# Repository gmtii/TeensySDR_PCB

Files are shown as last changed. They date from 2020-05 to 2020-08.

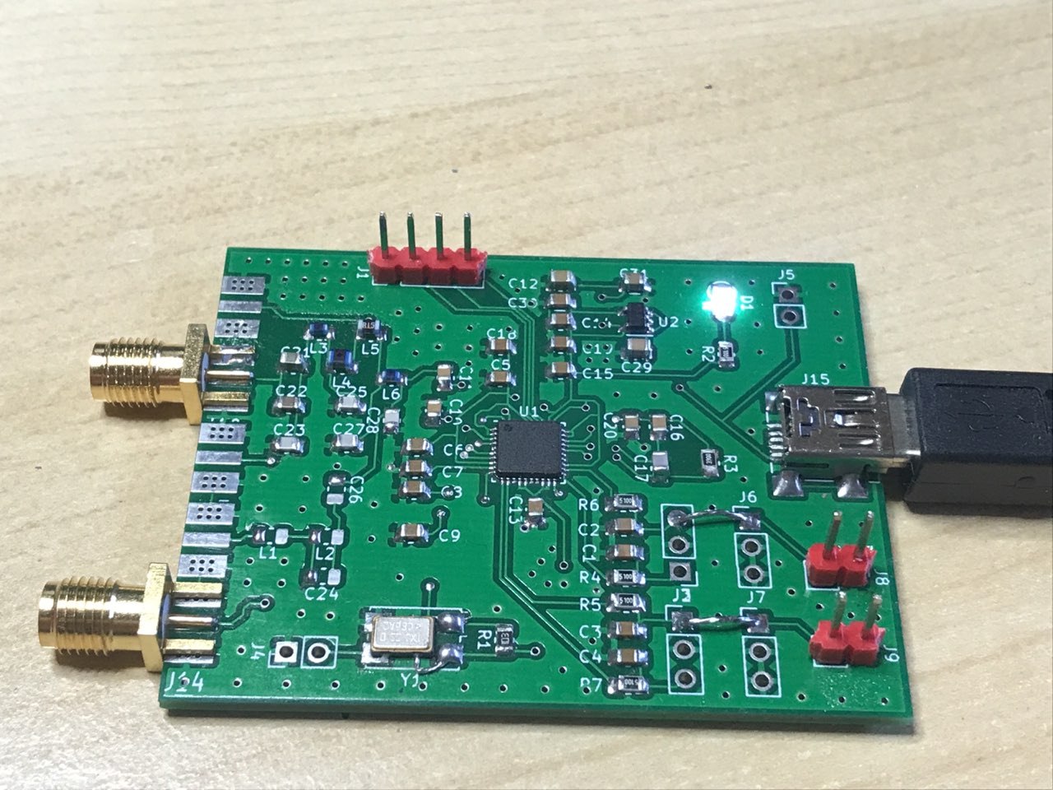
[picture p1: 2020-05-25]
ae8a2037-b399-4607-b648-da70b96b542e.jpg

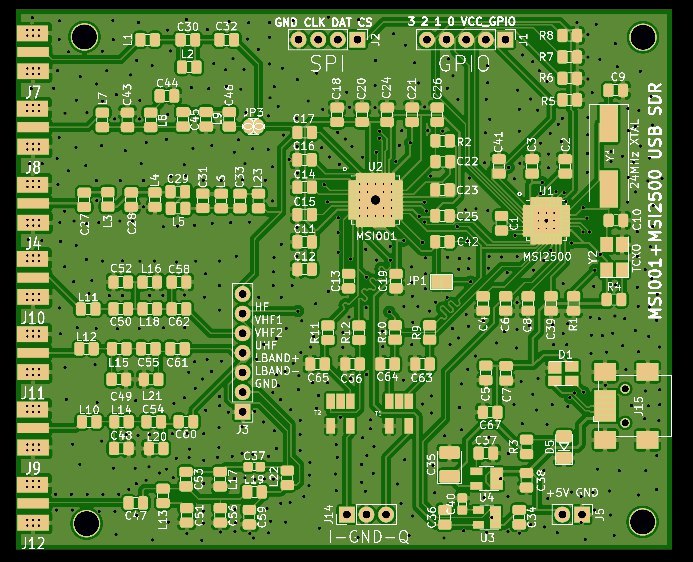
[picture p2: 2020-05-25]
e3250cb5-5ce9-4851-8bc5-c19debedf796.jpg

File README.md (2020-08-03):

# EA7GIB TeensySDR FRONTAL + MSI001 PCB gerbers and build instructions.

PCB TeensySDR Convolution DD4WH software repository : 

[Source link](https://github.com/DD4WH/Teensy-ConvolutionSDR)

Sources incluing msi001 support:

[MSI001 TeensySDR Convolution + MSI001 main source mod](https://github.com/gmtii/teensySDR)

Schematics + manual:

[Assembly instructions](https://github.com/gmtii/TeensySDR_PCB/blob/master/TEENSY_FINAL_v3.pdf)

Gerbers:

[Main PCB](https://github.com/gmtii/TeensySDR_PCB/blob/master/FRONTAL_TEENSY.zip)

[MSI001 IQ PCB + filters tipo 1](https://github.com/gmtii/TeensySDR_PCB/blob/master/MAIN_IQ_msi_tipo1.zip)

[MSI001 IQ PCB + filters tipo 2](https://github.com/gmtii/TeensySDR_PCB/blob/master/MAIN_IQ_msi_tipo2.zip)

3D enclosure sources:

[Front + black plate + buttons](https://github.com/gmtii/TeensySDR_PCB/blob/master/Tcaja-tensy.rar)
[MSI001 IQ PCB back plate version](https://github.com/gmtii/TeensySDR_PCB/blob/master/TAPA-teensy-MSI-modificada-.stl)

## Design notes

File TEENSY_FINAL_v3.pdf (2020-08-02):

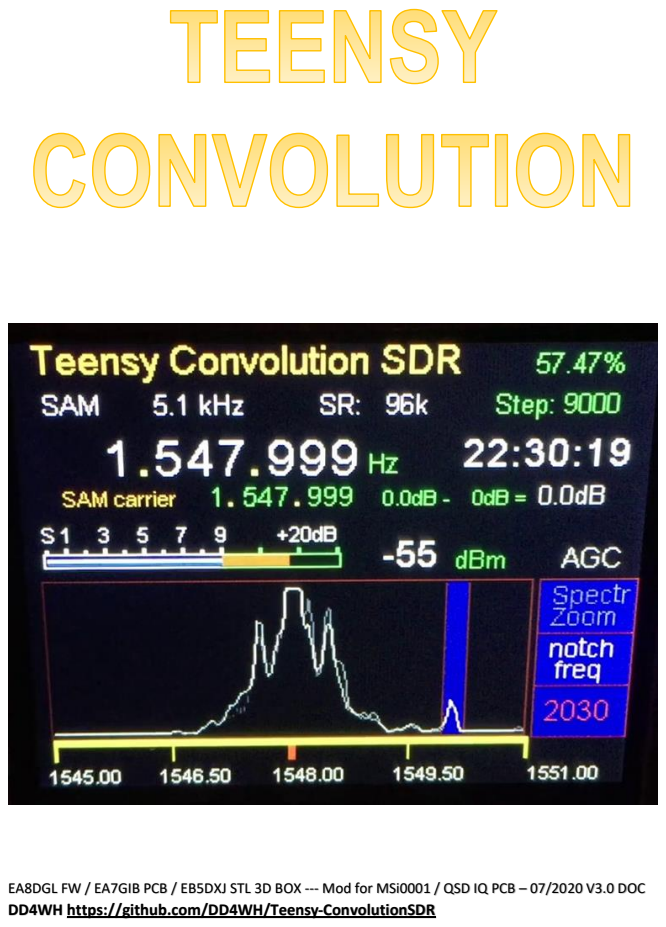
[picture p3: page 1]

EA8DGL FW / EA7GIB PCB / EB5DXJ STL 3D BOX --- Mod for MSi0001 / QSD IQ PCB – 07/2020 V3.0 DOC
DD4WH https://github.com/DD4WH/Teensy-ConvolutionSDR

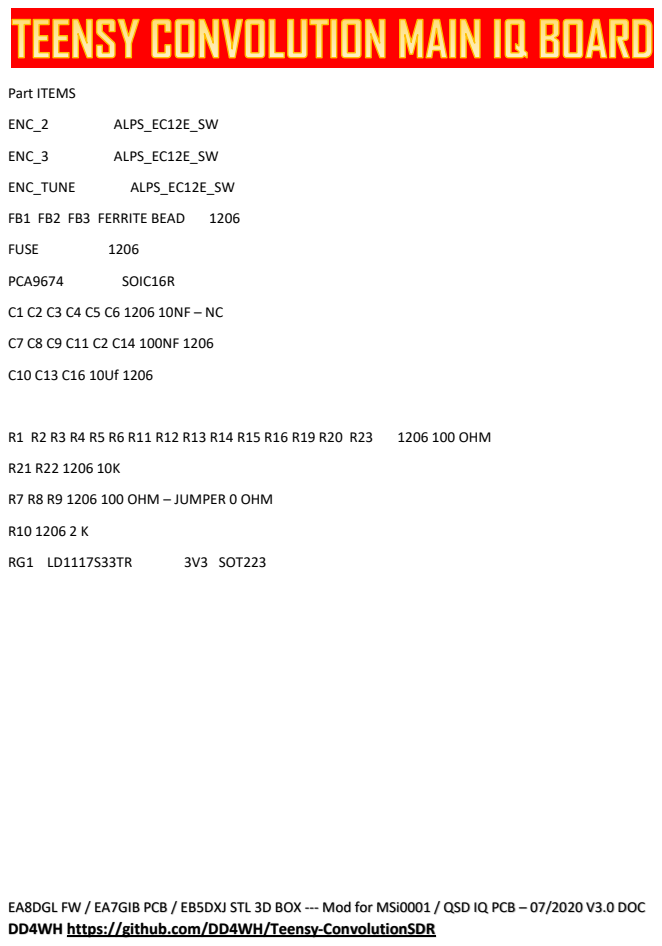
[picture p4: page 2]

EA8DGL FW / EA7GIB PCB / EB5DXJ STL 3D BOX --- Mod for MSi0001 / QSD IQ PCB – 07/2020 V3.0 DOC

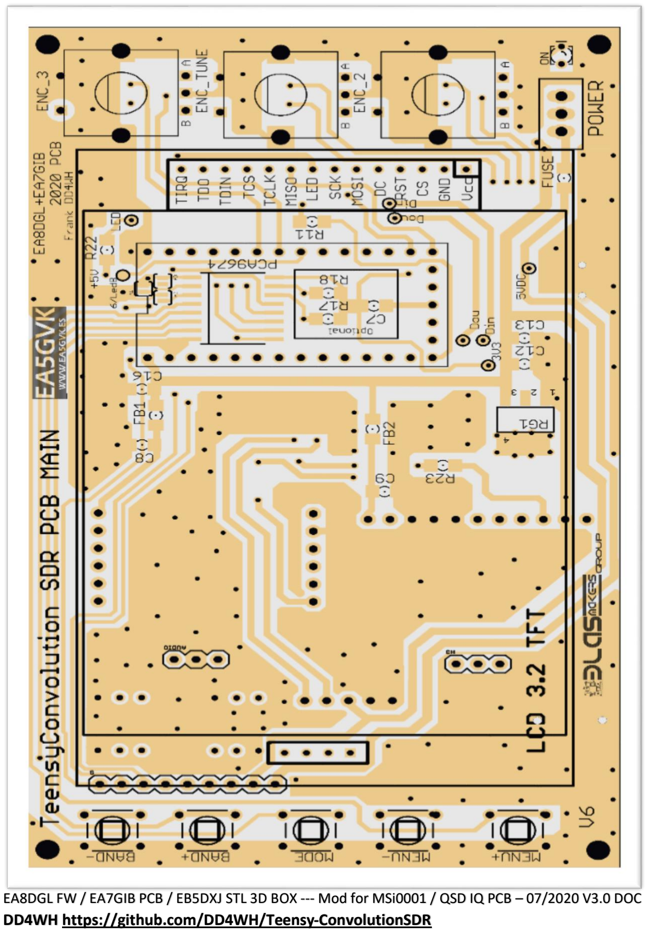
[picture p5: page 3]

EA8DGL FW / EA7GIB PCB / EB5DXJ STL 3D BOX --- Mod for MSi0001 / QSD IQ PCB – 07/2020 V3.0 DOC

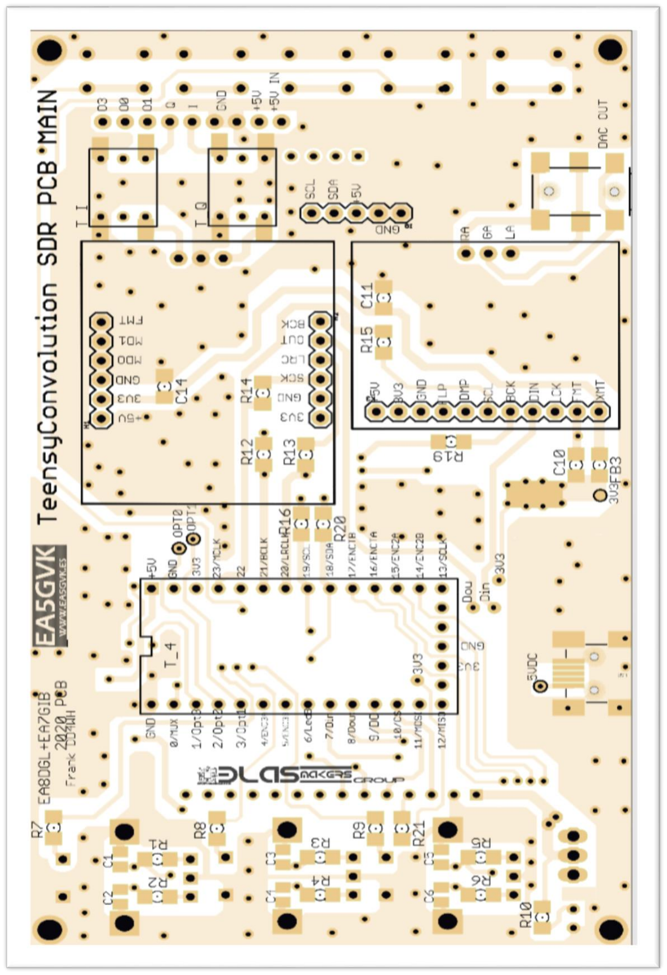
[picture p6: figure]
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

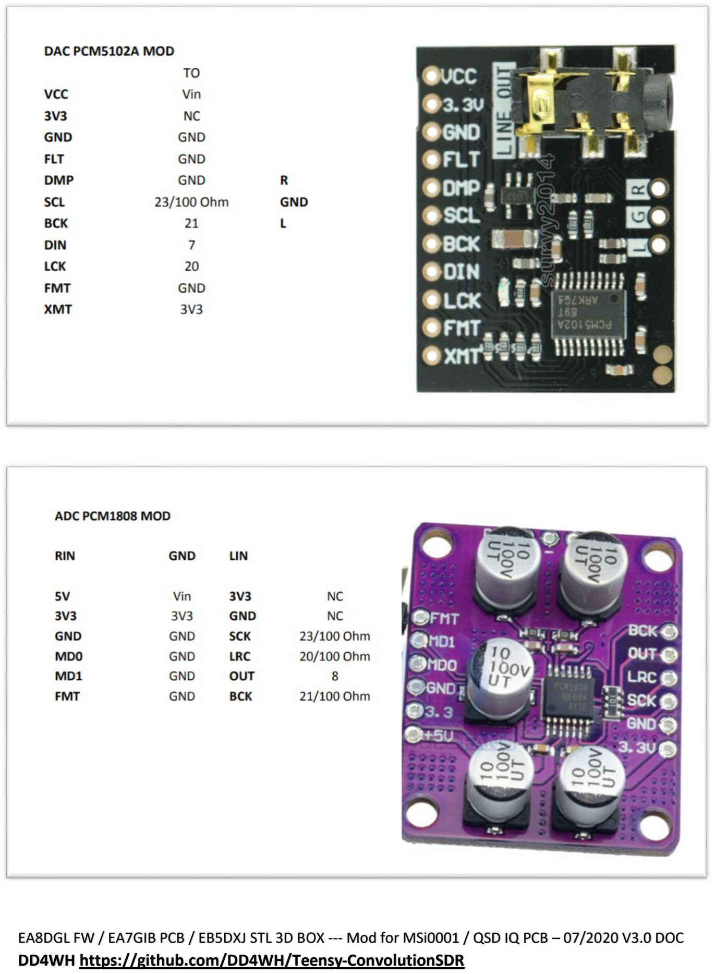
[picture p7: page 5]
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

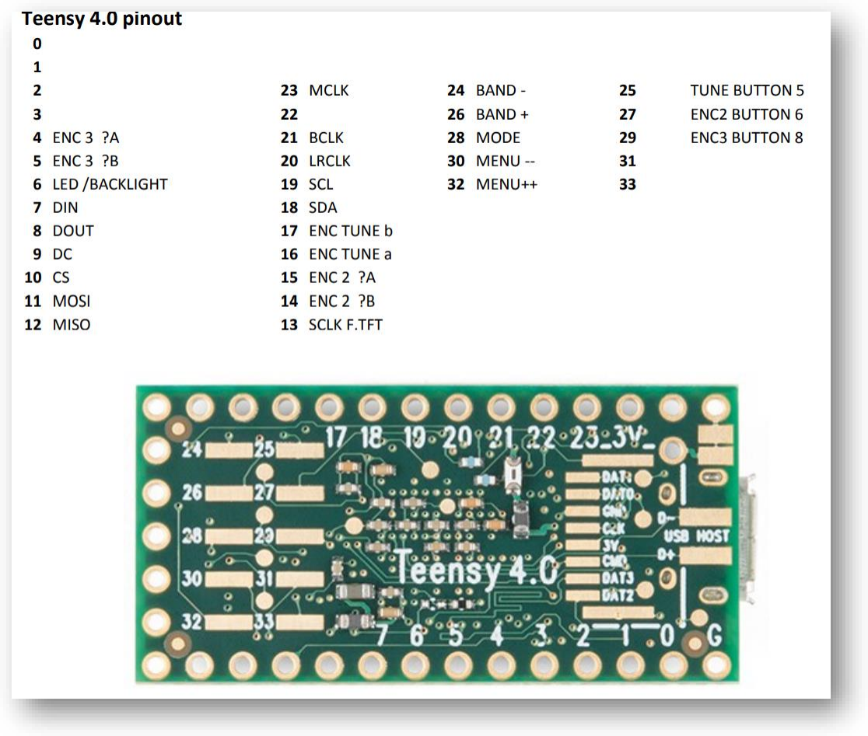
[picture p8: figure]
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

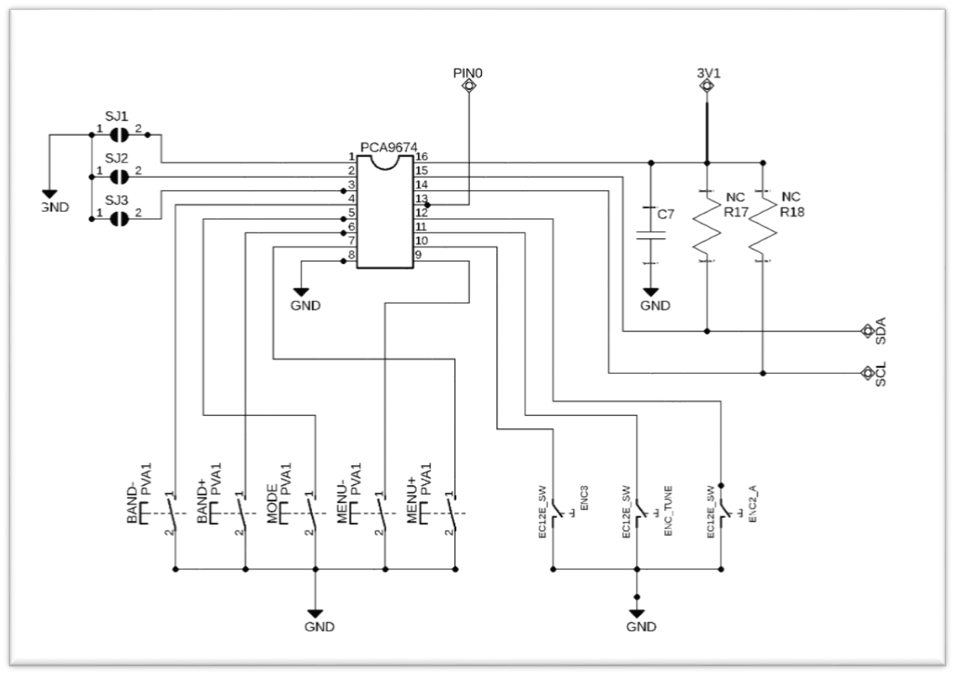
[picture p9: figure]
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

Mod. MUX for SW @EA8DGL FW

R17/R18 NC - SJ1-SJ3 CLOSE

Only for QSD IQ PCB - SOFT
S0 PIN 2 / S1 PIN 3 del T4

### 00 de 0-4 mhz

### 01 de 4 a 9 mhz

### 10 de 9 a 16 mhz

11 > 16 mhz

Only for MSi001 PCB - SOFT msi001_cs_pin = 1
msi001_dat_pin = 2
msi001_clk_pin = 3

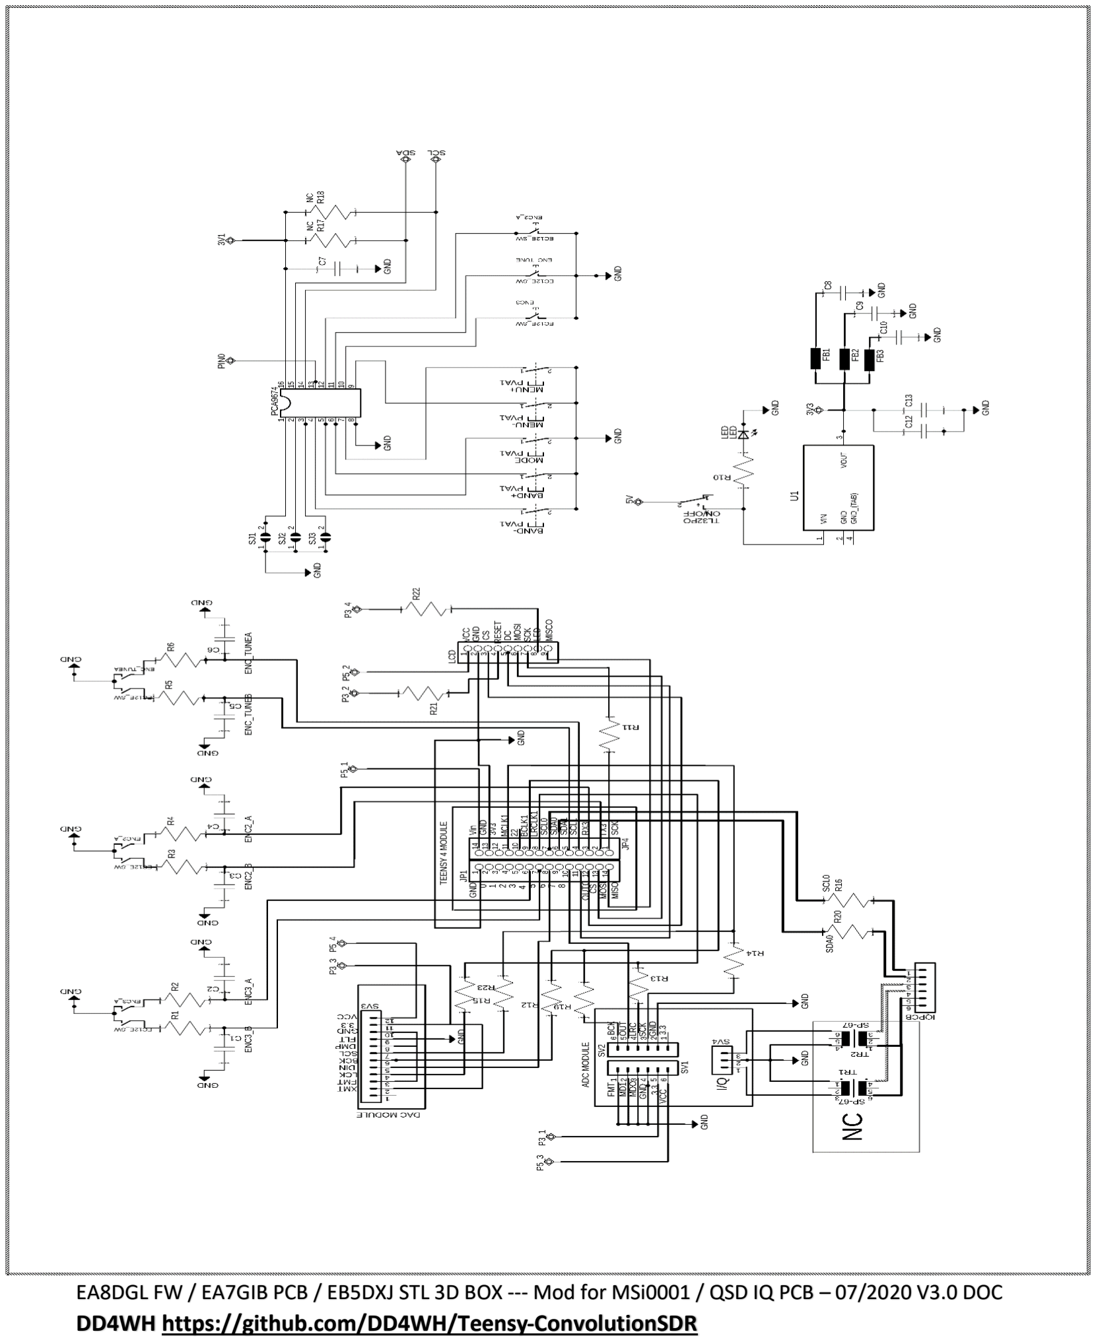
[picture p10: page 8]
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

PART NUMBER | PACK | VALUE

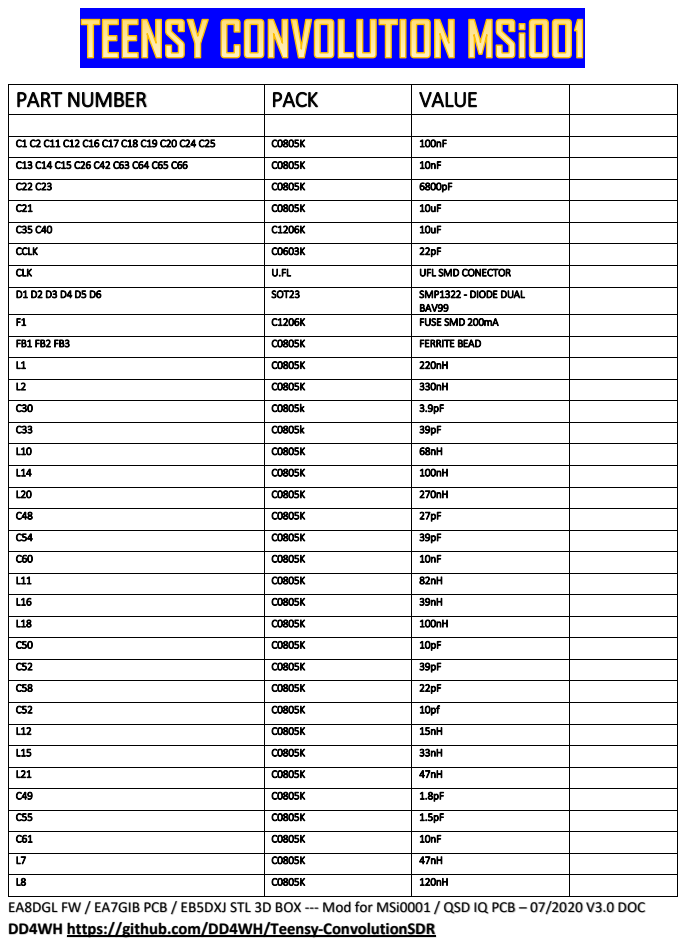
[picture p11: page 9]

CCLK | C0603K | 22pF

CLK | U.FL | UFL SMD CONECTOR

D1 D2 D3 D4 D5 D6 | SOT23 | SMP1322 - DIODE DUAL BAV99

F1 | C1206K | FUSE SMD 200mA

FB1 FB2 FB3 | C0805K | FERRITE BEAD

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

L9 | C0805K | 8.2nH
C43 | C0805K | 3.3pF
C44 | C0805K | 12pF
C45 | C0805K | 2.7pF
C46 | C0805K | 4.7pF
L13 | C0805K | 22nH
L17 | C0805K | 6.8nH
L19 | C0805K | 6.8nH
L22 | C0805K | 8.2nH
C47 | C0805K | 4.7pF
C51 | C0805K | 27pF
C53 | C0805K | 1.8pF
C56 | C0805K | 27pF
C57 | C0805K | 2.2pF
C59 | C0805K | 1.8pF
L3 | C0805K | 11uH | 2.2uH
L4 | C0805K | 220nH | 2.2uH
L5 | C0805K | 2.4uH | 560nH
L6 | C0805K | 390nH | 2.2uH
L23 | C0805K | 2.4uH | 2.2uH
C27 | C0805K | 30pF | 180pF
C28 | C0805K | 1.5nF | 180pF
C29 | C0805K | 130pF | 680pF
C31 | C0805K | 820pF | 180pF
C33 | C0805K | 130pF | 180pF
MSI001 | QFN-40 | MSi001
ON | SML1206 | LED
R2 | C0805K | 390
R4 | C0805K | 10K
R5 R6 R7 | C0805K | 100
R8 R9 R10 R12 | C0805K | 510
R11 | C0805K | 2K2
TCXO | 5.2X3.4-4-PAD | 22Mhz
U4 REG 3V3 max 5.5 V. In. | SOT23-5 | LD398M33 / MIC5205 3V3 SMD TLV73333PDBVT
C3 | C0805K | 100nF
C5 | C1206K

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

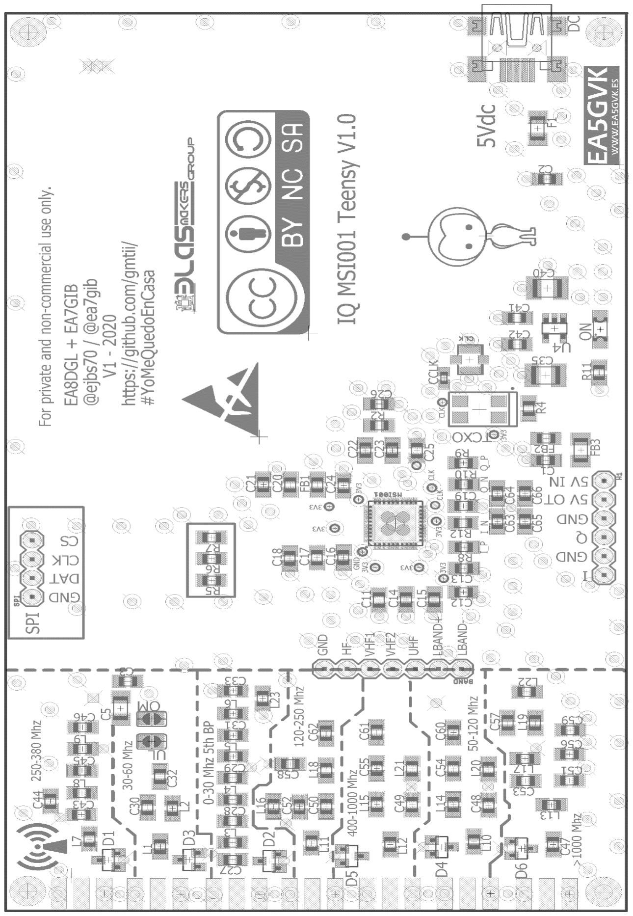
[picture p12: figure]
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

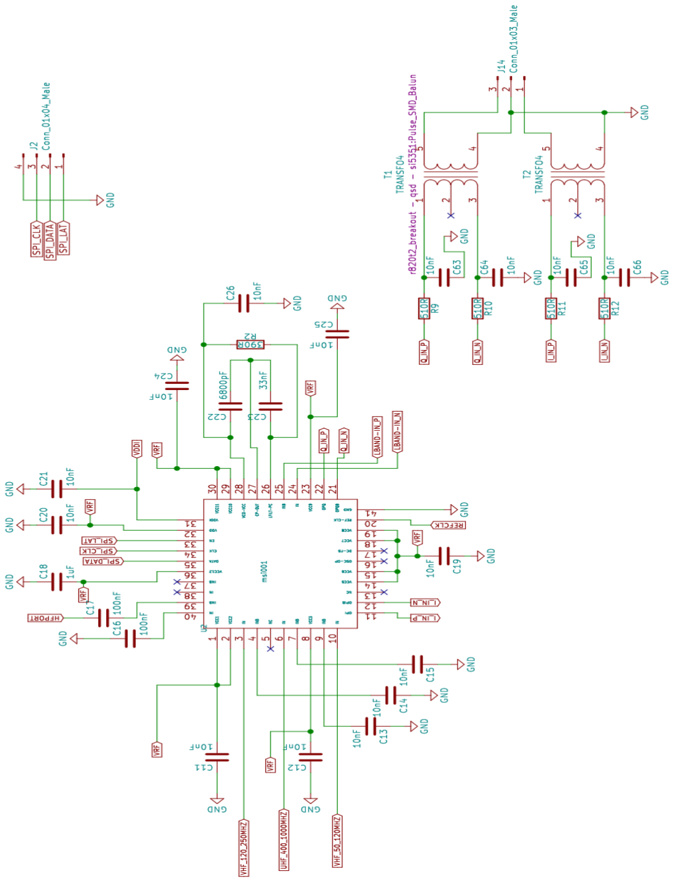
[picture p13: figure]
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

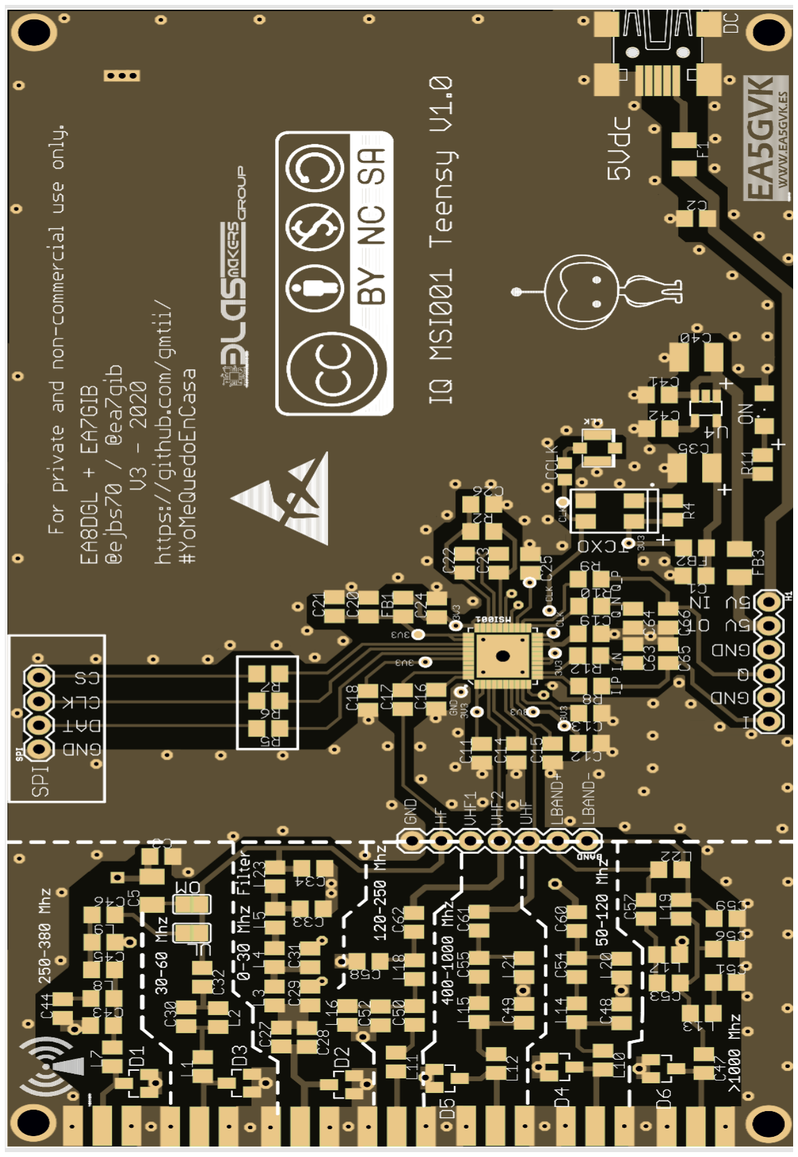
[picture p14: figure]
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

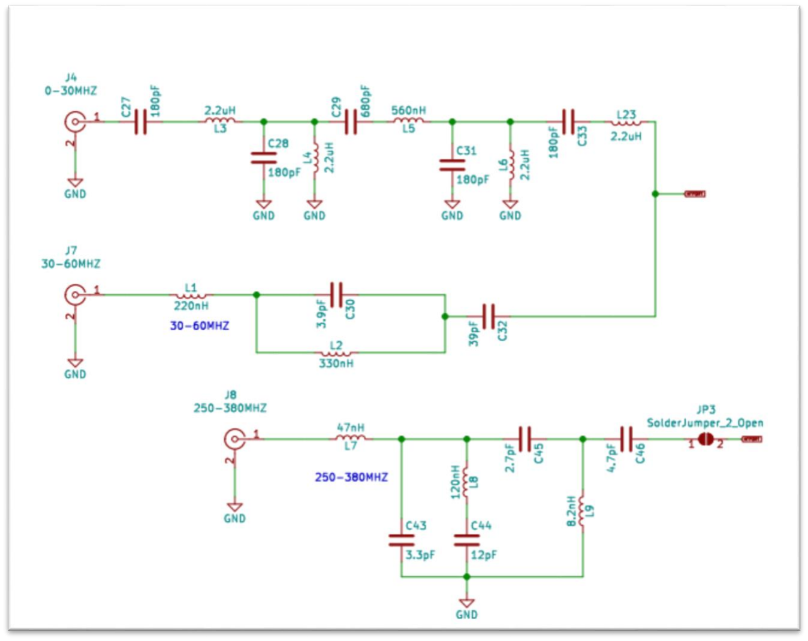
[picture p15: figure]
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

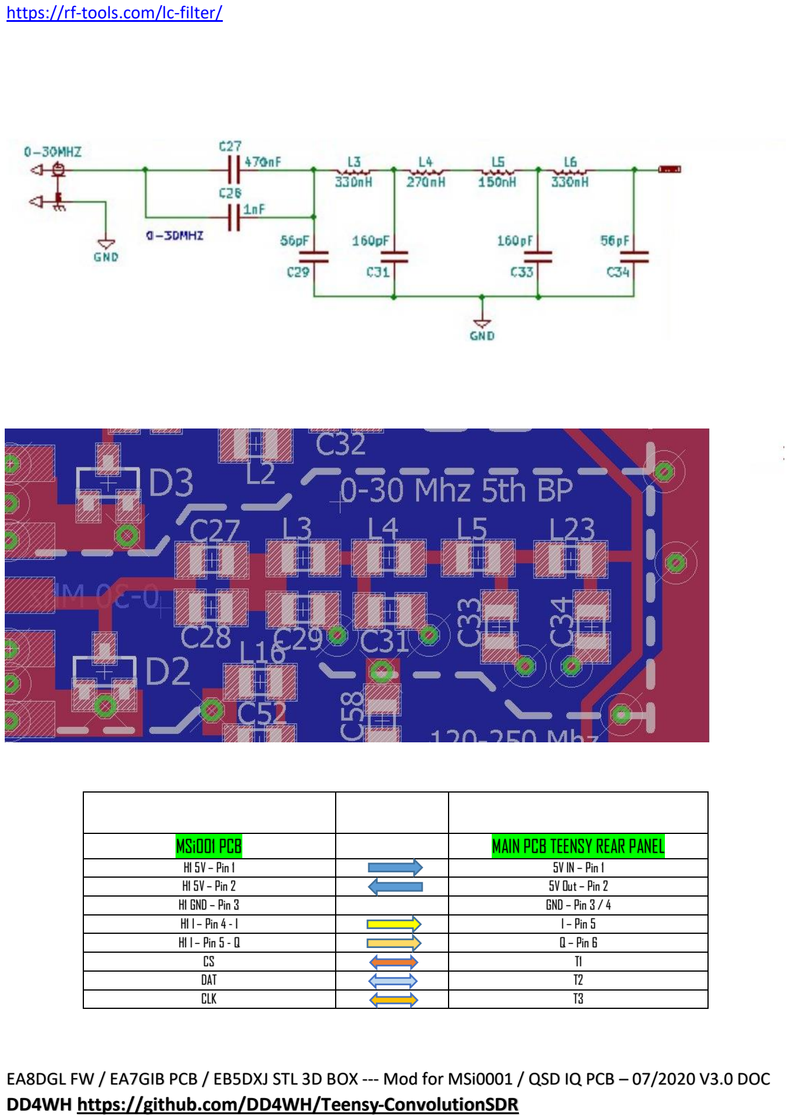
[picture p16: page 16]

EA8DGL FW / EA7GIB PCB / EB5DXJ STL 3D BOX --- Mod for MSi0001 / QSD IQ PCB – 07/2020 V3.0 DOC https://rf-tools.com/lc-filter/

MSi001 PCB | MAIN PCB TEENSY REAR PANEL
H1 5V – Pin 1 | 5V IN – Pin 1
H1 5V – Pin 2 | 5V Out – Pin 2
H1 GND – Pin 3 | GND – Pin 3 / 4
H1 I – Pin 4 - I | I – Pin 5
H1 I – Pin 5 - Q | Q – Pin 6
CS | T1
DAT | T2
CLK | T3

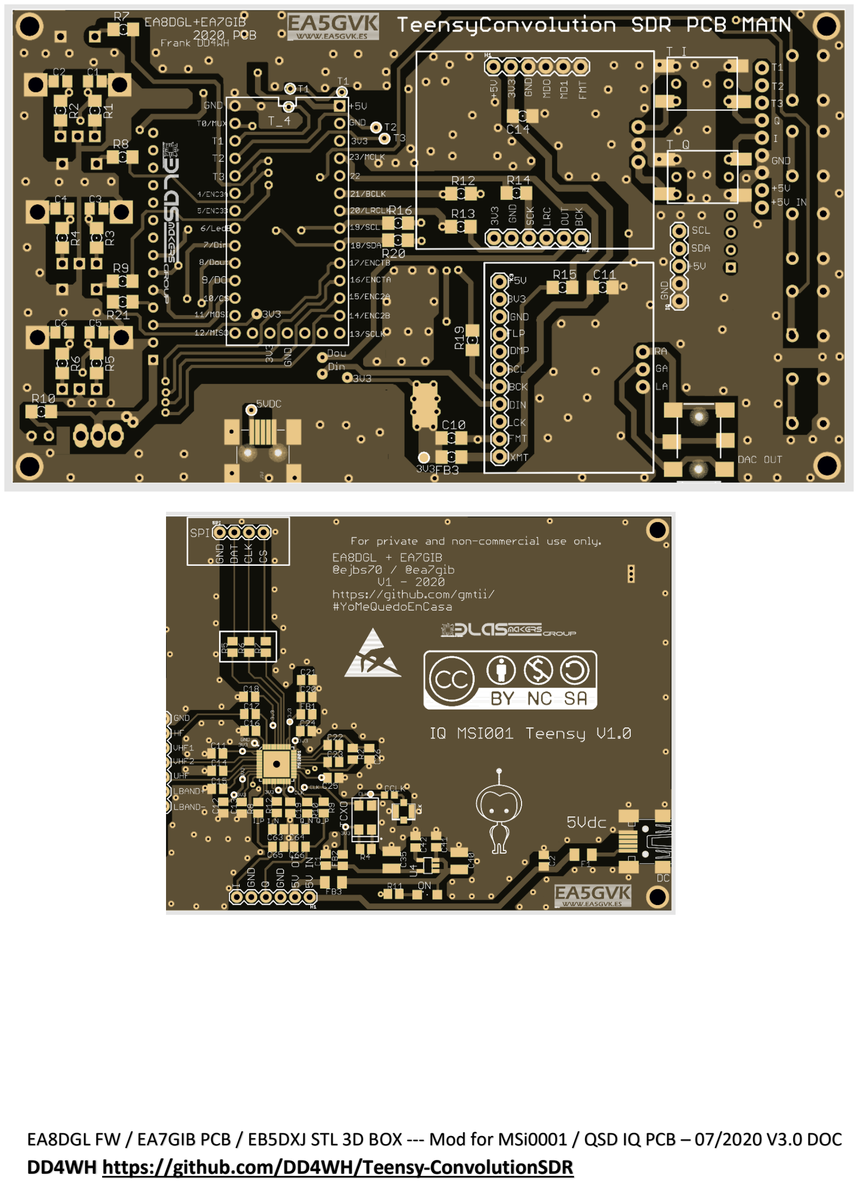
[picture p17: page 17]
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

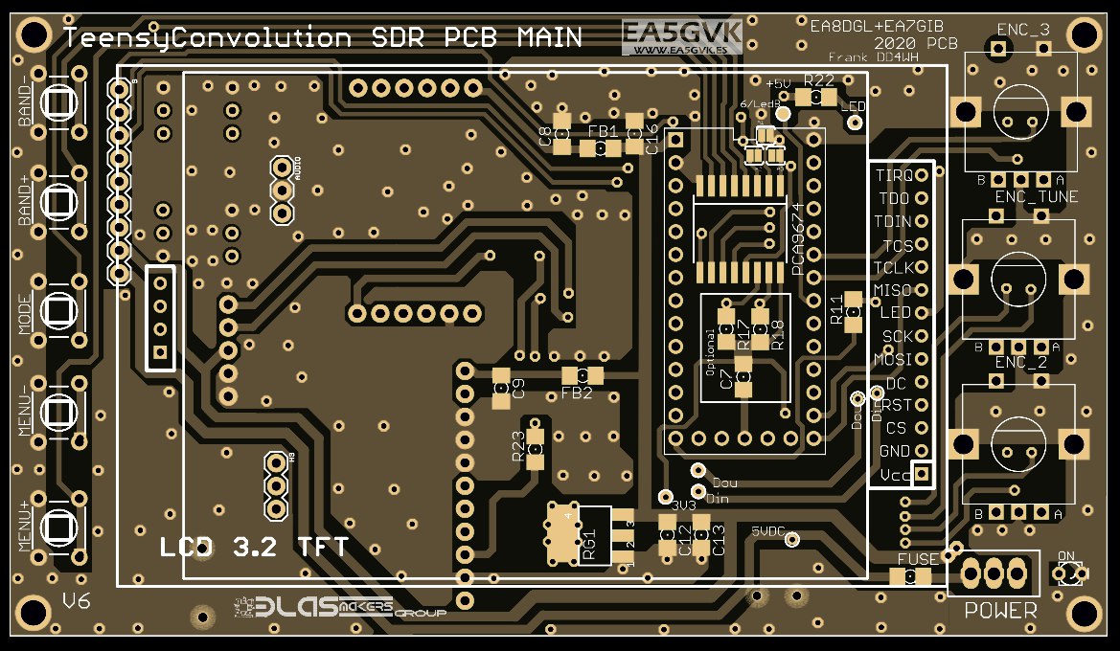
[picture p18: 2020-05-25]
ef99af62-868f-4970-847a-df3a93e9a39b.jpg

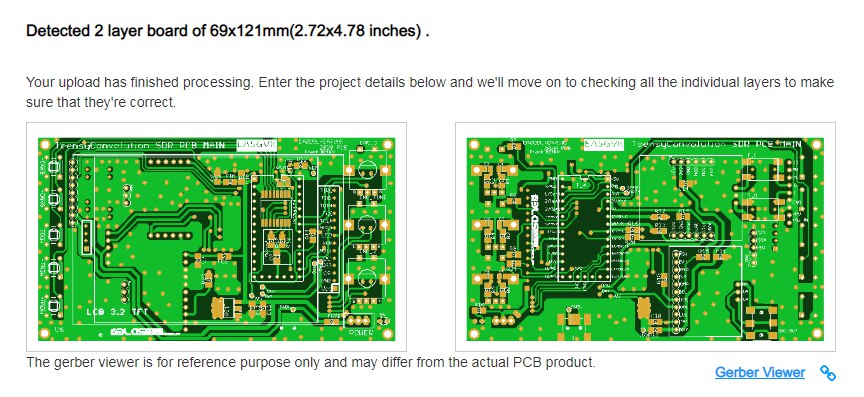
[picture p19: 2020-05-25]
02e6eca1-ae3c-434b-8e3b-802277b04a9b.jpg

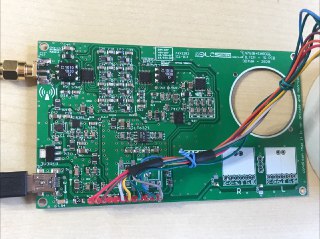
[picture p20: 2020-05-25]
0c04fc78-4b23-4a34-ace4-05e1ae427119.jpg

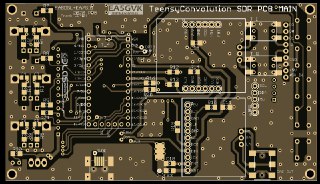
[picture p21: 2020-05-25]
0c644886-0f54-410e-9ede-cd83abfa7673.jpg

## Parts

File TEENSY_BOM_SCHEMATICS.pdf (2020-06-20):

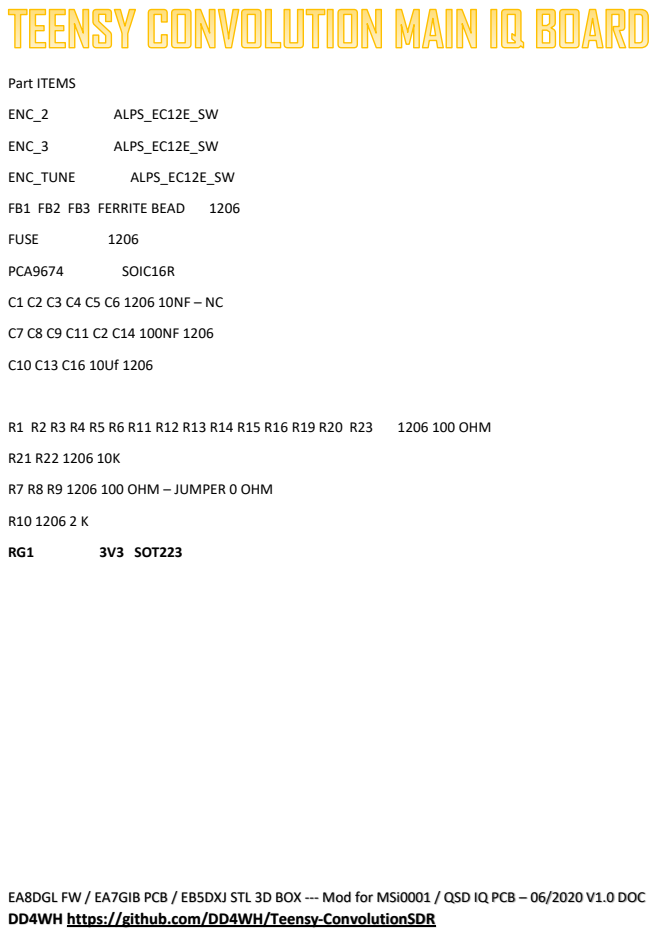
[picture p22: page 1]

EA8DGL FW / EA7GIB PCB / EB5DXJ STL 3D BOX --- Mod for MSi0001 / QSD IQ PCB – 06/2020 V1.0 DOC
DD4WH https://github.com/DD4WH/Teensy-ConvolutionSDR

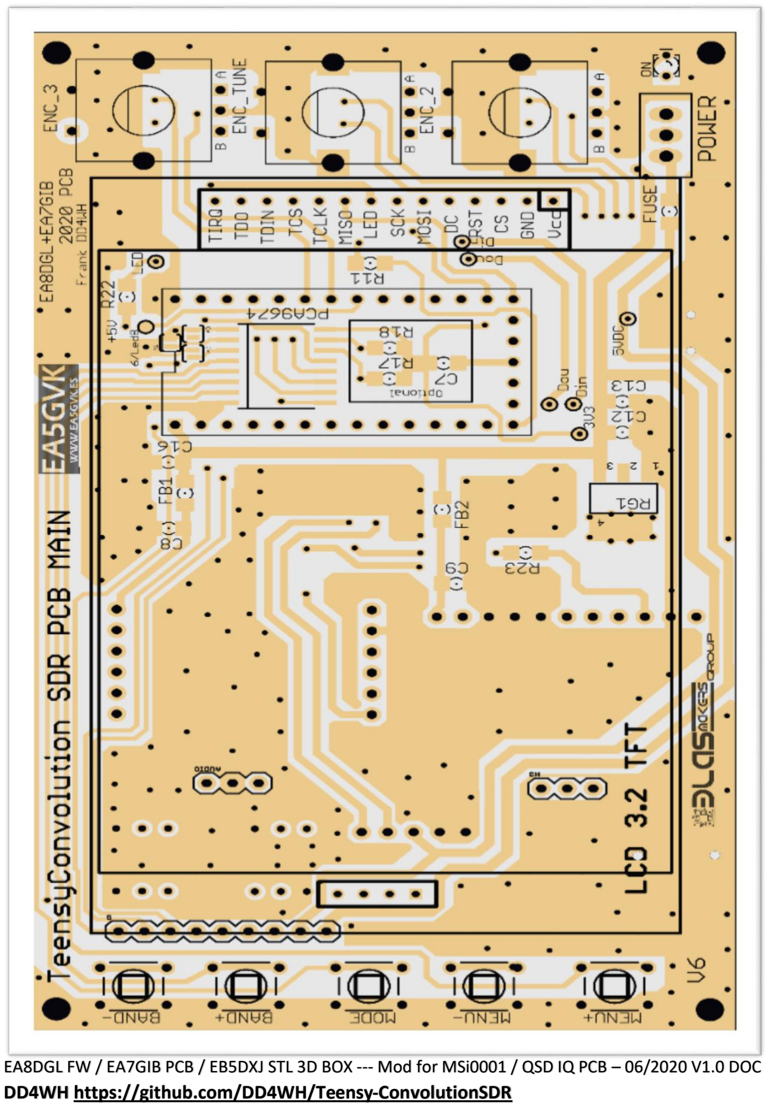
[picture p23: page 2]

EA8DGL FW / EA7GIB PCB / EB5DXJ STL 3D BOX --- Mod for MSi0001 / QSD IQ PCB – 06/2020 V1.0 DOC


EA8DGL FW / EA7GIB PCB / EB5DXJ STL 3D BOX --- Mod for MSi0001 / QSD IQ PCB – 06/2020 V1.0 DOC

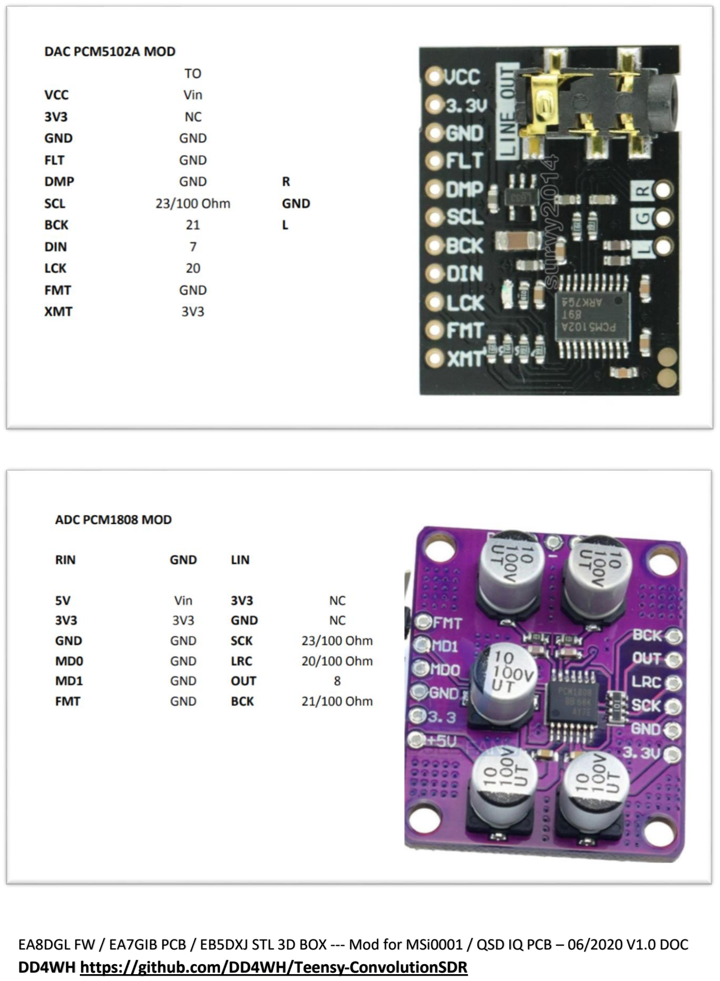
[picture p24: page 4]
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

Mod. MUX for SW @EA8DGL FW

R17/R18 NC

SJ1-SJ3 CLOSE

Only for QSD IQ PCB - SOFT S0 PIN 2 / S1 PIN 3 del T4

### 00 de 0-4 mhz

### 01 de 4 a 9 mhz

### 10 de 9 a 16 mhz

11 > 16 mhz

Only for MSi001 PCB - SOFT msi001_cs_pin = 1
msi001_dat_pin = 2
msi001_clk_pin = 3

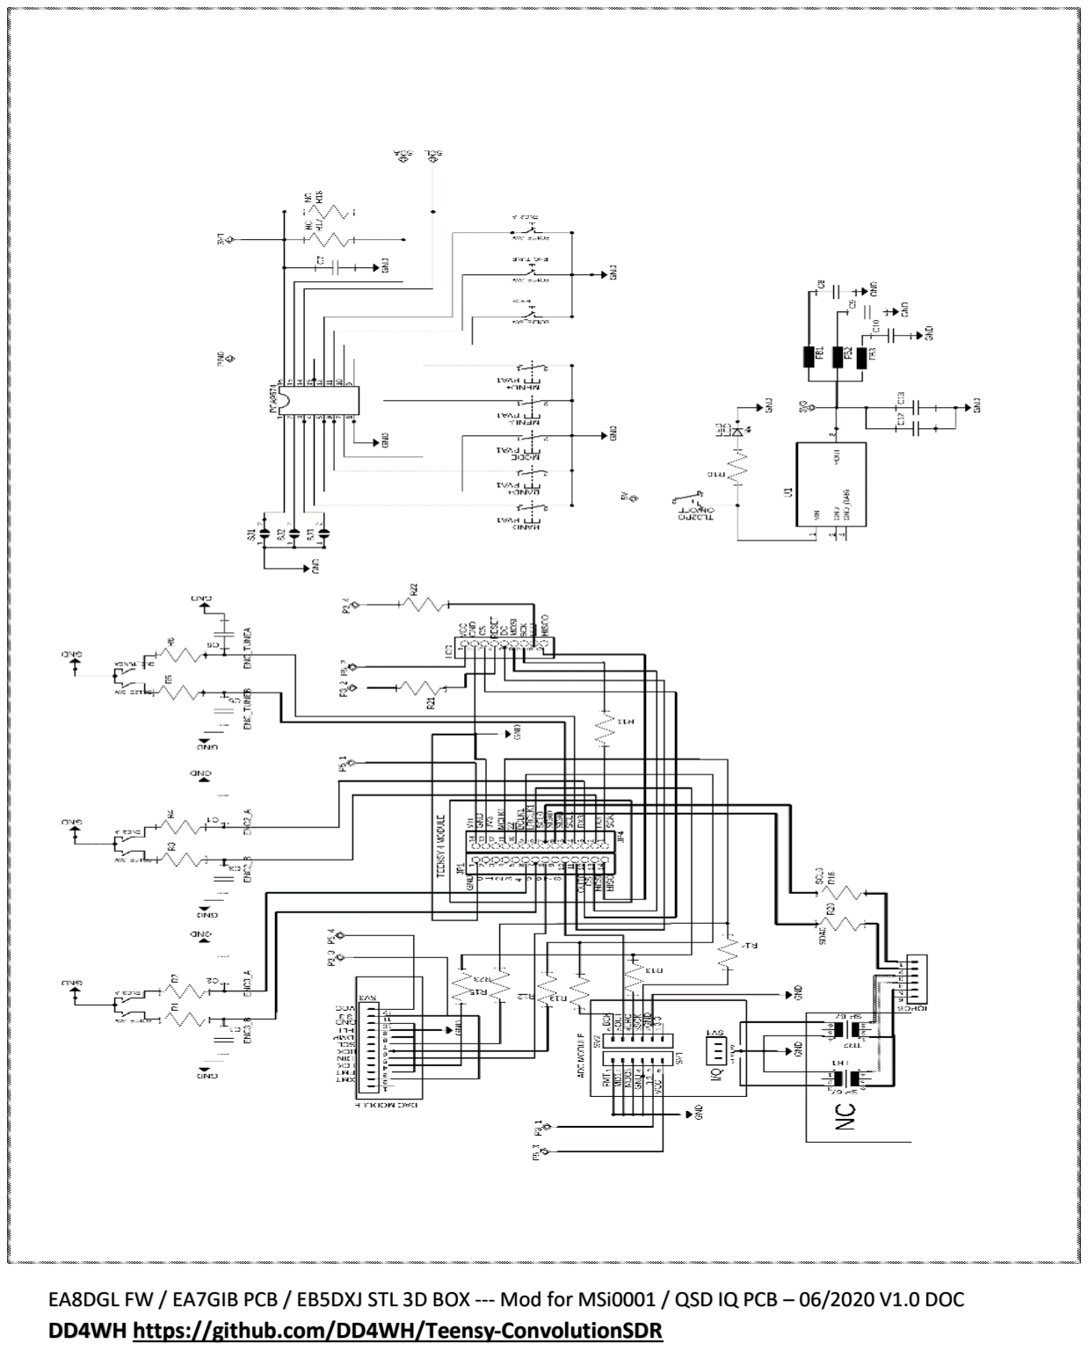
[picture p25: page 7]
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

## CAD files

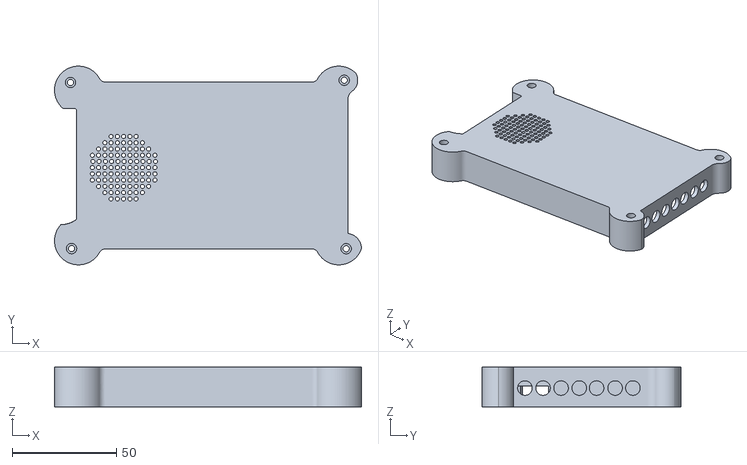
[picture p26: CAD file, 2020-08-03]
TAPA-teensy-MSI-modificada-.stl
147.1 x 95.2 x 19.0

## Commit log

2020-06-20 Bom and parts placement
2020-08-02 Fixed ldo msi pcb big y
